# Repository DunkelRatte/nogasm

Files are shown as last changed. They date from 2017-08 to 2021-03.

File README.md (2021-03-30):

# Nogasm

This is a fork of the [original nogasm project](https://github.com/nogasm/nogasm).

## Hardware

### Board

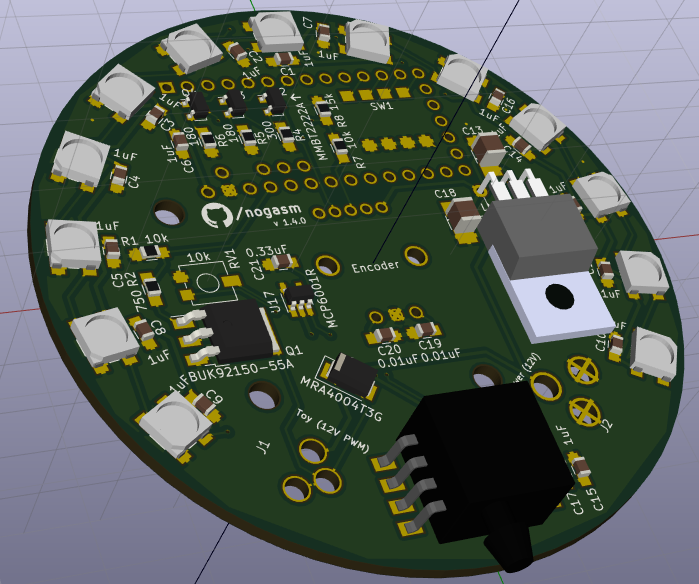
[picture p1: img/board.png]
Board render


Count | Name | Digikey link | Comment |
-----|--------|-------------|---------|
1 | Teensy LC | https://www.digikey.com/short/31cn1n ||
13 | WS2812b RGB LED | https://www.digikey.com/short/31c04r ||
1 | MP3V5050GP | https://www.digikey.com/short/31c04n ||
1 | PEL12T-4225S-S1024 (COM-10982 encoder, backlit) | https://www.digikey.com/short/31cn19 ||
1 | COM-10597 (encoder knob, transparent) | https://www.digikey.com/short/djdq9jpq ||
1 | MCP6001RT-I/OT | https://www.digikey.com/short/31cnvz ||
1 | CGRA4004-G | https://www.digikey.com/short/31c0mw ||
1 | BUK92150-55A | https://www.digikey.com/short/31cnvb ||
3 | MMBT2222A | https://www.digikey.com/short/bmf4f7fn ||
1 | LM7805CT/NOPB | https://www.digikey.com/short/wcn5wvbh | SMD versions more common now |
2 | 10µF 20V tantalum cap 1206 | https://www.digikey.com/short/4pf7p859 || 
15 | 1µF 16V ceramic cap 0805 | https://www.digikey.com/short/31cdcp ||
1 | 0.33µF 16V ceramic cap 0603 | https://www.digikey.com/short/31cdt4 ||
3 | 10nF 16V ceramic cap 0805| https://www.digikey.com/short/31cd7f ||
1 | 10k Ohm trimmer | https://www.digikey.com/short/31cnvv ||
1 | 15k Ohm resistor 0805 | https://www.digikey.com/short/31c04h ||
2 | 10k Ohm resistor 0805 | https://www.digikey.com/short/31cdt9 ||
2 | 750 Ohm resistor 0805 | https://www.digikey.com/short/31cdtw ||
1 | 300 Ohm resistor 0805 | https://www.digikey.com/short/31c04q ||
2 | 180 Ohm resistor 0805 | https://www.digikey.com/short/31cdtn ||
1 | 4pos DIP switch | https://www.digikey.com/short/31cn1m ||
1 | Barreljack socket 1.3mm/3.5mm | https://www.digikey.com/short/31c0mt ||
1 | Barreljack plug 1.3mm/3.5mm | https://www.digikey.com/short/31c0mj ||
1 | Barreljack socket 2.5mm/5.5mm | https://www.digikey.com/short/31c0mh ||

[You can order all of the above parts in one cart from Digikey](https://www.digikey.com/short/d32z5423)

#### Aisler Kit
[You can order PCBs and/or all parts as a single kit on Aisler](https://aisler.net/DunkelRatte/nogasm/board)

#### Power
You'll need 12V/1.5A DC power supply with a 2.5mm/5.5mm barreljack plug (or fitting to above bigger socket).

### Vibrator
The case is designed for a RS-555 motor. [Aliexpress lists several versions](https://www.aliexpress.com/wholesale?SearchText=rs555).
You'll need to press a weight onto it.

Other 12V DC toys controlable with PWM and using up to 2A should work as well.

### Plug
An inflatable buttplug is used for pressure detection. For example "*Fanny Hill*" by *Seven Creations*.

## Software

### Flashing the teensy

[Install the Teensy Loader Application](https://www.pjrc.com/teensy/loader.html).
After There are two ways to get the firmware onto the device:

#### Flashing the compiled .hex
This is the easiest way. Download the `.hex` file and use the loader to upload the file to the device.

#### Compiling the code yourself
[Download and install Teensyduino](https://www.pjrc.com/teensy/td_download.html).
Afterwards get the sourcecode, compile and upload it via the arduino IDE.

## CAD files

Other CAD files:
blender/COM08034.blend
blender/MP3V5050.blend
blender/pj-031dh.blend
blender/ws2812b.blend

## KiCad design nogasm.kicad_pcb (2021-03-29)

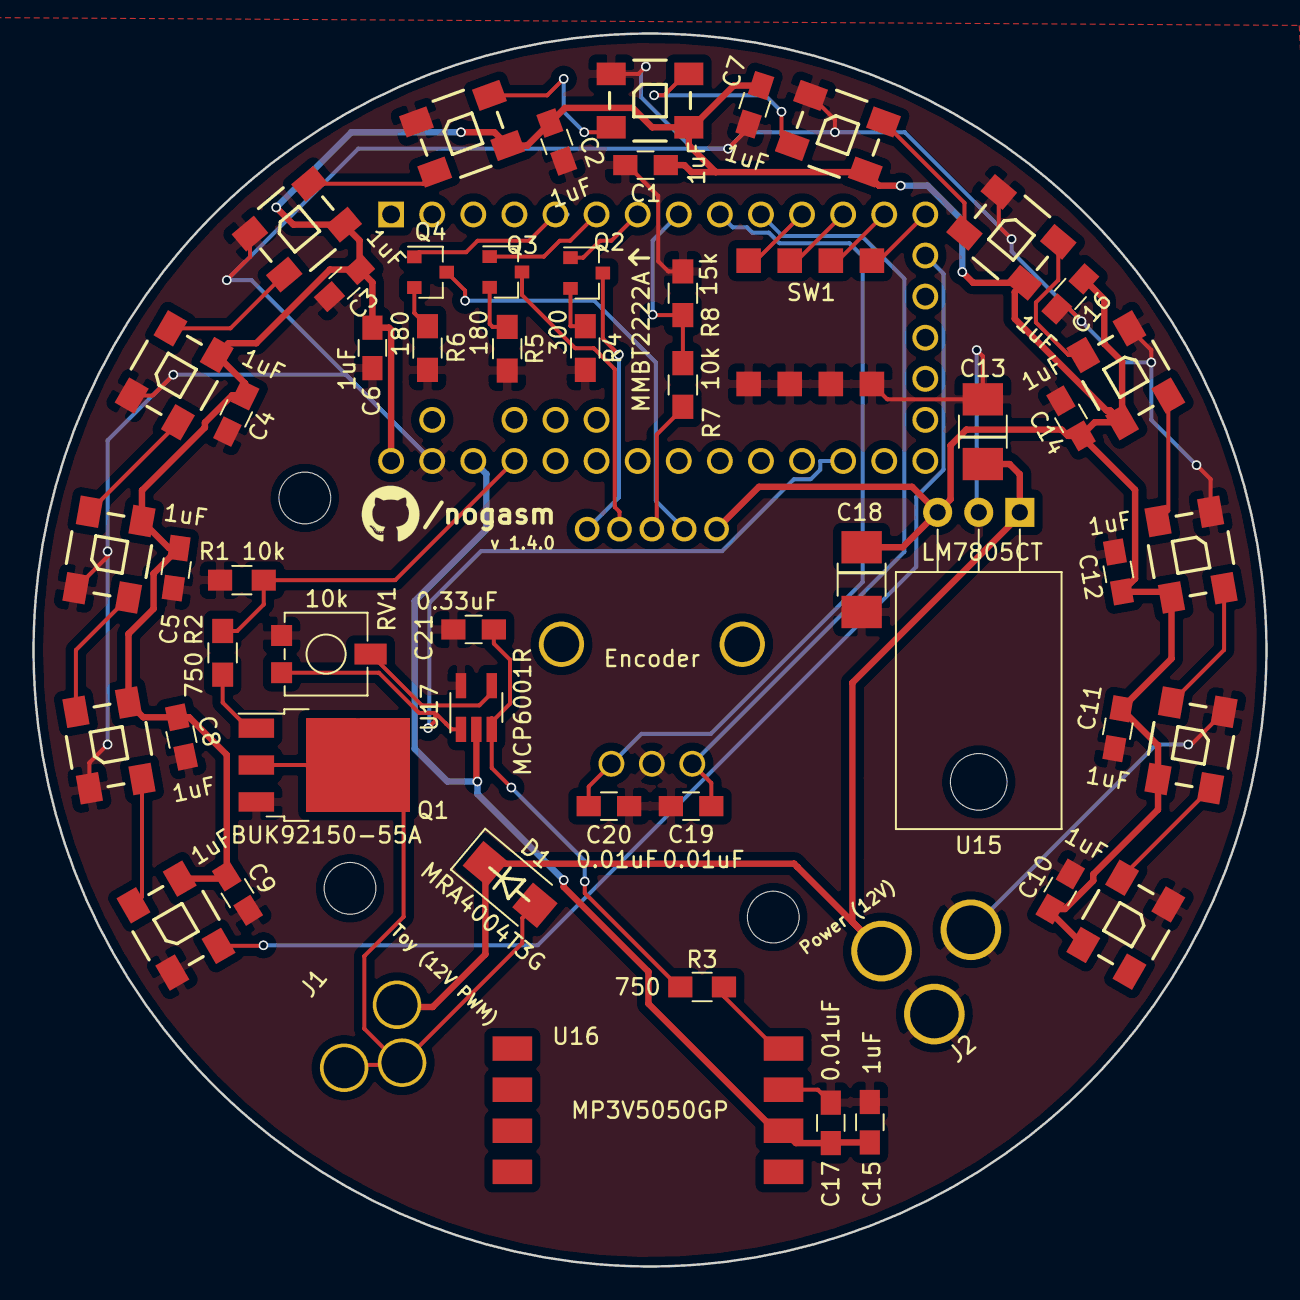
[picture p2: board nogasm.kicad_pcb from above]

Board: 2 copper layers, 76.2 x 76.2 mm, 56 parts (1 on the bottom side), 41 nets.

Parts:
C1, C2, C3, C4, C5, C6, C7, C8, C9, C10, C11, C12, C14, C15, C16: 1uF; C_0805_HandSoldering
C13, C18: 10uF; C_1210_HandSoldering
C17, C19, C20: 0.01uF; C_0805_HandSoldering
C21: 0.33uF; C_0805_HandSoldering
D1: MRA4004T3G; D_SMA_0202
Encoder: Rotary_Encoder_Switch_RGB; COM-10982
J1: DC Jack PJ-031DH 3.5mm; Barreljack_3mm
J2: DC Jack PRT-10811; Barreljack_5.4mm
Q1: BUK92150-55A; TO-252-3_TabPin2
Q2, Q3, Q4: MMBT2222A; SOT-23
R1, R7: 10k; R_0805_HandSoldering
R2, R3: 750; R_0805_HandSoldering
R4: 300; R_0805_HandSoldering
R5, R6: 180; R_0805_HandSoldering
R8: 15k; R_0805_HandSoldering
RV1: 10k; Potentiometer_Trimmer_Vishay_TS53YL
SW1: SW_DIP_x04; SW_DIP_4_SMD
U1, U2, U3, U4, U5, U6, U7, U8, U9, U10, U11, U12, U13: WS2812B
U14: Teensy-LC; Teensy30_31_32_LC
U15: LM7805CT; TO-220_Horizontal
U16: MP3V5050GP
U17: MCP6001R; SOT-23-5_HandSoldering

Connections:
+3V3: C15.1, C17.1, U14.31, U16.2, U17.2
+5V: C1.1, C2.1, C3.1, C4.1, C5.1, C6.2, C7.1, C8.1, C9.1, C10.1, C11.1, C12.1, C14.1, C16.1, C18.1, Encoder.5, U1.1, U2.1, U3.1, U4.1, U5.1, U6.1, U7.1, U8.1, U9.1, U10.1, U11.1, U12.1, U13.1, U14.33, U15.3
+12V: C13.1, D1.1, J1.1, J2.1, U15.1
/5VIO: U1.4, U14.15
/ENC_A: C20.1, Encoder.A, U14.9
/ENC_B: C19.1, Encoder.B, U14.10
/ENC_Bl: Q4.1, U14.5
/ENC_Gr: Q3.1, U14.6
/ENC_Rd: Q2.1, U14.7
/ENC_SW: R7.2, R8.1, U14.8
/V_PRES: RV1.1, U14.22, U17.1
GND: C1.2, C2.2, C3.2, C4.2, C5.2, C6.1, C7.2, C8.2, C9.2, C10.2, C11.2, C12.2, C13.2, C14.2, C15.2, C16.2, C17.2, C18.2, C19.2, C20.2, C21.2, Encoder.C, J2.2, J2.3, Q1.3, R1.1, R4.2, R5.2, R6.2, R8.2, RV1.3, SW1.1, SW1.2, SW1.3, SW1.4, U1.3, U2.3, U3.3, U4.3, U5.3, U6.3, U7.3, U8.3, U9.3, U10.3, U11.3, U12.3, U13.3, U14.32, U15.2, U16.3, U17.5
unnamed: C21.1, R3.1, U17.3
unnamed: D1.2, J1.2, J1.3, Q1.2
unnamed: Q1.1, R2.1
unnamed: Q2.2, R4.1
unnamed: Encoder.1, Q2.3
unnamed: Q3.2, R5.1
unnamed: Encoder.2, Q3.3
unnamed: Q4.2, R6.1
unnamed: Encoder.4, Q4.3
unnamed: R1.2, R2.2, U14.30
unnamed: R3.2, U16.4
unnamed: Encoder.3, R7.1
unnamed: RV1.2, U17.4
unnamed: SW1.5, U14.14
unnamed: SW1.6, U14.13
unnamed: SW1.7, U14.12
unnamed: SW1.8, U14.11
unnamed: U1.2, U2.4
unnamed: U2.2, U3.4
unnamed: U3.2, U4.4
unnamed: U4.2, U5.4
unnamed: U5.2, U6.4
unnamed: U6.2, U7.4
unnamed: U7.2, U8.4
unnamed: U8.2, U9.4
unnamed: U10.2, U11.4
unnamed: U9.2, U10.4
unnamed: U11.2, U12.4
unnamed: U12.2, U13.4

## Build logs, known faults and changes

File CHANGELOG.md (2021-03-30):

# Changelog

## 3/29/2021

- DigiKey 5.x, Teensy lib as git submodule
- Adjusted parts list to use parts currently available on digikey.com

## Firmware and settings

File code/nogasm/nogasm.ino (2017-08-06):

#include <Encoder.h>
#include <EEPROM.h>
#include "FastLED.h"
#include "RunningAverage.h"


#define DEBUG false     // Display debug data on serial monitor
#define DEBUG_PLOT true // Display debug data on serial plotter

//=======Hardware Setup===============================
//Pressure Sensor Analog In
#define BUTTPIN 15 // Pressure sensor
#define MOTPIN 23 // Motor
//LEDs
#define NUM_LEDS 13
#define LED_PIN 17 //5V buffered pin on Teensy LC, single wire data out to WS8212Bs
#define LED_TYPE    WS2812B
#define COLOR_ORDER GRB
#define BRIGHTNESS 10 //Subject to change, limits current that the LEDs draw
CRGB leds[13];
//Encoder
#define REDPIN   5 //RGB pins of the encoder LED
#define GREENPIN 4
#define BLUEPIN  3
#define ENC_SW   6 //Pushbutton on the encoder
Encoder encoder(8, 7); //Quadrature inputs on pins 7,8
//DIP Switches
#define SW1PIN 12 //Dip switch pins, for setting software options without reflashing code
#define SW2PIN 11
#define SW3PIN 10
#define SW4PIN 9


//Update/render period
#define period (1000/FREQUENCY)
#define FREQUENCY 60 //Update frequency in Hz

//Running pressure average array length and update frequency
#define RA_HIST_SECONDS 25
#define RA_FREQUENCY 6
#define RA_TICK_PERIOD (FREQUENCY / RA_FREQUENCY)
RunningAverage raPressure(RA_FREQUENCY*RA_HIST_SECONDS);

#define MOT_MAX_SPEED 256
#define MOT_MIN_SPEED 40

#define COOLDOWN_TIME 1000

////=======State Machine Modes=========================
#define State_MANUAL    0
#define State_AUTO      1
#define State_OPT_SPEED 2

#define ButtonMode_NONE  0
#define ButtonMode_SHORT 1
#define ButtonMode_LONG  2

#define ButtonState_UP   0
#define ButtonState_DOWN 1


int avgPressure = 0; //Running 25 second average pressure
float motSpeed = 0; //Motor speed, 0-255 (float to maintain smooth ramping to low speeds)
int sampleTick = 0;
float maximumDelta = 0.0;
int state = State_MANUAL;
int buttonMode = ButtonMode_NONE;

int lastButtonState = ButtonState_UP;
int buttonPressTimestamp = 0;
int cooldownUntil = 0;

int get_button_state() {
    return digitalRead(ENC_SW) ? ButtonState_DOWN : ButtonState_UP;
}

float get_pressure_percentage_of(float max) {

    int delta = (get_sensor() - avgPressure);
    if(delta == 0) { delta = 1;};
    return min(1.0, delta / max);
}

void update_button_mode() {
    if( ButtonState_DOWN == lastButtonState &&
        ButtonState_UP   == get_button_state()) { //  released

        lastButtonState = ButtonState_UP;
        int presstime = millis() - buttonPressTimestamp;

        buttonMode =  (presstime < 500) ? ButtonMode_SHORT : ButtonMode_LONG;
        return;
    }

    if( ButtonState_UP   == lastButtonState &&
        ButtonState_DOWN == get_button_state()) { // pressed down

        buttonPressTimestamp = millis();
        lastButtonState = ButtonState_DOWN;
    }
    
    buttonMode = ButtonMode_NONE; // nothing yet
}

void check_button() {
    if(buttonMode != ButtonMode_NONE) {
        switch (buttonMode) {
            case ButtonMode_SHORT:
                next_state();
                break;
            case ButtonMode_LONG:
                break;
        }

        buttonMode = ButtonMode_NONE;
    }
}

void next_state() {
    state += 1;
    state = state % 2;
}

void run_selected_mode() {
    switch (state) {
        case State_MANUAL:
            mode_manual();
            break;
        case State_AUTO:
            mode_auto();
            break;
    }
}

bool is_cooldown() {
    return millis() < cooldownUntil;
}

void mode_auto() {
    showKnobRGB(CRGB::Blue);

    float sensitivityStep = maximumDelta / 51;

    int delta = get_sensor() - avgPressure;
    int knob = get_encoder(0, 51);
    float stopDelta = max(1.0, maximumDelta - (knob * sensitivityStep));

    if(stopDelta < 1.0) {
        stopDelta = 1;
    }

    draw_bar(get_pressure_percentage_of(stopDelta));
    draw_multilevel_cursor(knob);

    if(delta > stopDelta) {
        cooldownUntil = millis() + COOLDOWN_TIME;
        motSpeed = 0;
    }

    if(!is_cooldown()) {
        float motIncrement = 0.1;
        motSpeed += motIncrement;
    }
}

void mode_manual() {
    showKnobRGB(CRGB::Purple);

    int knob = get_encoder(0, 51);
    motSpeed = (knob == 0) ? 0 : map(knob, 1, 51, MOT_MIN_SPEED, MOT_MAX_SPEED);
    draw_bar(get_pressure_percentage_of(maximumDelta));
    draw_multilevel_cursor(knob);

}
void showKnobRGB(const CRGB& rgb) {
    digitalWrite(REDPIN,   (rgb.r > 0 ? HIGH : LOW) );
    digitalWrite(GREENPIN, (rgb.g > 0 ? HIGH : LOW) );
    digitalWrite(BLUEPIN,  (rgb.b > 0 ? HIGH : LOW) );
}

void beep_motor(int f1, int f2, int f3){
    if(motSpeed > 245) analogWrite(MOTPIN, 245); //make sure the frequency is audible
    else if(motSpeed < 10) analogWrite(MOTPIN, 10);
    analogWriteFrequency(MOTPIN, f1);
    delay(250);
    analogWriteFrequency(MOTPIN, f2);
    delay(250);
    analogWriteFrequency(MOTPIN, f3);
    delay(250);
    analogWriteFrequency(MOTPIN, 440);
    analogWrite(MOTPIN,motSpeed);
}

void draw_bar(float percentage) {
    CRGB colors[] = {
            CRGB::Green,
            CRGB::Green,
            CRGB::Green,
            CRGB::Green,
            CRGB::Green,
            CRGB::Green,
            CRGB::Green,
            CRGB::Green,
            CRGB::Green,
            CRGB::Yellow,
            CRGB::Orange,
            CRGB::Red,
            CRGB::Red
    };

    for(int i = 0; i < floor(percentage * 13); i++) {
        leds[i] = colors[i];
    }
}

//Draw a "cursor", one pixel representing either a pressure or encoder position value
void draw_cursor(int pos,CRGB C1){
    pos = constrain(pos,0,NUM_LEDS-1);
    leds[pos] = C1;
}

void draw_multilevel_cursor(int pos) {
    CRGB colors[] = {CRGB::Blue, CRGB::Green, CRGB::Yellow, CRGB::Red};
    pos = min(pos, 52);
    int level = floor(pos / NUM_LEDS);
    int p = pos % (NUM_LEDS);
    draw_cursor(p, colors[level]);
}

//Draw 3 revolutions of bars around the LEDs. From 0-39, 3 colors
void draw_bars_3(int pos,CRGB C1, CRGB C2, CRGB C3){
    pos = constrain(pos,0,NUM_LEDS*3-1);
    int colorNum = pos/NUM_LEDS; //revolution number
    int barPos = pos % NUM_LEDS; //place on circle, from 0-12
    switch(colorNum){
        case 0:
            fill_gradient_RGB(leds,0,C1,barPos,C1);
            //leds[barPos] = C1;
            break;
        case 1:
            fill_gradient_RGB(leds,0,C1,barPos,C2);
            break;
        case 2:
            fill_gradient_RGB(leds,0,C2,barPos,C3);
            break;
    }
}

//Provide a limited encoder reading corresponting to tacticle clicks on the knob.
//Each click passes through 4 encoder pulses. This reduces it to 1 pulse per click
int get_encoder(int minVal, int maxVal){
    if(encoder.read()>maxVal*4)encoder.write(maxVal*4);
    else if(encoder.read()<minVal*4) encoder.write(minVal*4);
    return constrain(encoder.read()/4,minVal,maxVal);
}

void set_motor_speed() {
    if(motSpeed > 1) {
        motSpeed = max(motSpeed, MOT_MIN_SPEED); // skip the slow values
    }
    motSpeed = min(motSpeed, MOT_MAX_SPEED);
    analogWrite(MOTPIN, (int) motSpeed);
}

int get_sensor() {
    return analogRead(BUTTPIN);
}

void update_sensor_average() {
    sampleTick++; //Add pressure samples to the running average slower than 60Hz
//    if (sampleTick % RA_TICK_PERIOD == 0) {
    if (sampleTick % 50 == 0) {
        raPressure.addValue(get_sensor());
        avgPressure = raPressure.getAverage();
    }
}

void fade_leds() {
    fadeToBlackBy(leds,NUM_LEDS,20);
}

void update_leds() {
    FastLED.show();
}

void check_sensor_maxing_out() {
    //Alert that the Pressure voltage amplifier is railing, and the trim pot needs to be adjusted
    if(analogRead(BUTTPIN) > 4030) {
        //beep_motor(2093,2093,2093); //Three high beeps
    }
}

void debug_print_data() {
    if(DEBUG) {
        Serial.println("----------------------");
        Serial.print("Average pressure: "); Serial.println(avgPressure);
        Serial.print("Motor speed: "); Serial.println(motSpeed);
        Serial.print("Button pressed: "); Serial.println(get_button_state());
        Serial.print("State: "); Serial.println(state);
        Serial.print("Is cooling down: "); Serial.println(is_cooldown());
    }
    
    if(DEBUG_PLOT) {
        Serial.print(avgPressure);
        Serial.print(",");
        Serial.print(get_sensor());
        
        Serial.println("");
    }
}

void setup(){
    pinMode(REDPIN,   OUTPUT); //Connected to RGB LED in the encoder
    pinMode(GREENPIN, OUTPUT);
    pinMode(BLUEPIN,  OUTPUT);
    pinMode(ENC_SW,   INPUT);

    pinMode(SW1PIN,   INPUT); //Set DIP switch pins as inputs
    pinMode(SW2PIN,   INPUT);
    pinMode(SW3PIN,   INPUT);
    pinMode(SW4PIN,   INPUT);

    digitalWrite(SW1PIN, HIGH); //Enable pullup resistors on DIP switch pins.
    digitalWrite(SW2PIN, HIGH); //They are tied to GND when switched on.
    digitalWrite(SW3PIN, HIGH);
    digitalWrite(SW4PIN, HIGH);

    pinMode(MOTPIN,OUTPUT); //Enable "analog" out (PWM)

    pinMode(BUTTPIN,INPUT); //default is 10 bit resolution (1024), 0-3.3
    analogReadRes(12); //changing ADC resolution to 12 bits (4095)
    analogReadAveraging(32); //To reduce noise, average 32 samples each read.

    raPressure.clear(); //Initialize a running pressure average

    digitalWrite(MOTPIN, LOW);//Make sure the motor is off


    FastLED.addLeds<LED_TYPE, LED_PIN, COLOR_ORDER>(leds, NUM_LEDS).setCorrection(TypicalLEDStrip);
    FastLED.setBrightness(BRIGHTNESS);

    maximumDelta = 4096.0 - get_sensor();

    delay(1000); // 1 second delay for recovery


    Serial.begin(115200);

    beep_motor(1047,1396,2093);

    mode_manual();
}

void loop() {
    static int sampleTick = 0;
    //Run this section at the update frequency (default 60 Hz)
    if (millis() % period == 0) {
        delay(1);

        update_button_mode();
        check_button();
        
        run_selected_mode();

        update_sensor_average();
        check_sensor_maxing_out();

        fade_leds();
        update_leds();

        set_motor_speed();
        debug_print_data();
    }
}

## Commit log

2017-05-17 Squashed 'kicad-library/' content from commit fbfcf3a1
    git-subtree-dir: kicad-library
    git-subtree-split: fbfcf3a1d5e57af7e85bbe38c28fd9cc36468816
    [1593K_Enclosure.kicad_pcb, 1593K_Enclosure.sch, Arduino_As_Uno.kicad_pcb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]
2017-05-17 initial commit with data
    [MP3V5050.blend, nogasm.kicad_pcb, nogasm.sch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]
2017-05-18 changing DIP switch to SMD and fixing some library linking
    [nogasm.kicad_pcb, nogasm.sch]
2017-05-18 rerouting some caps to front copper
    [nogasm.kicad_pcb]
2017-05-26 adding proper barrel jack footprints and using them on the board
    [COM08034.blend, nogasm.kicad_pcb, nogasm.sch]
2017-06-01 fixing pad size of C13 and C 18. Fixing wrong D1 polarity
    [nogasm.kicad_pcb, nogasm.sch]
2017-06-01 fixing BUK pinout
    [nogasm.kicad_pcb, nogasm.sch]
2017-07-21 fixing cap polarity marking on silkscreen
    [nogasm.kicad_pcb]
2017-07-21 removing silkscreen for drillholes and increasing version number
    [nogasm.kicad_pcb]
2017-07-21 fixing wrong connected ENC_B / ENC_Bl nets
    [nogasm.kicad_pcb, nogasm.sch]
2017-07-31 fixing unconnected net and some pcb layout changes
    [nogasm.kicad_pcb, nogasm.sch]
2017-08-01 layouting LEDs with proper angular distance
    [nogasm.kicad_pcb]
2017-08-01 renaming LEDs
    [nogasm.sch]
2017-08-06 updating readme regarding power
2017-08-06 adding board render image
2021-03-28 Support KiCAD 5.x; include gerber files
    [1593K_Enclosure.kicad_pcb, 1593K_Enclosure.sch, Arduino_As_Uno.kicad_pcb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]
2021-03-29 Updated BoM
